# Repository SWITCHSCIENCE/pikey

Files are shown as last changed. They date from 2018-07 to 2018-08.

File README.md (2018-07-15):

# Pikey

This is 30 keys Keyboard and enclosure with integrated stand for Raspberry Pi 2,3,3+ and 3.5 inch display.

* PCB
	* Gerber data
	* KiCad project
	* Schematic
	* Artwork
	* BOM
* Firmware
	* QMK Keyboard source file
* Document
	* Not yet.
* 3D model
	* STL file
	* [Tinkercad](https://www.tinkercad.com/things/kkT37oe7HXW)

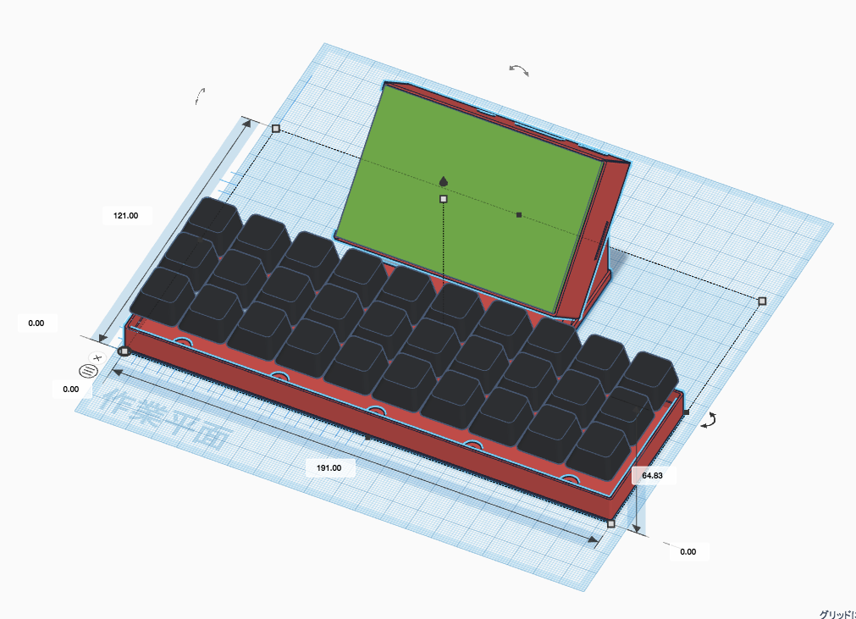
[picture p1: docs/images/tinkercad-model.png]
完成予定


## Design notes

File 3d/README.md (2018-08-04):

3x10 Cherry MX compatible Keyboard with Raspberry Pi and several kind of displays.

* PikeyHiPix4
	Pimoroni HyperPixel 4
	https://www.tinkercad.com/things/fxrJvk6TXBG

* PikeyHyPix3.5
	Pimoroni HyperPixel 3.5
	https://www.tinkercad.com/things/kfZhMOrKK17

* PikeyUCtronics3.5
	UCtronics 3.5
	https://www.tinkercad.com/things/gSCO0fujyfa

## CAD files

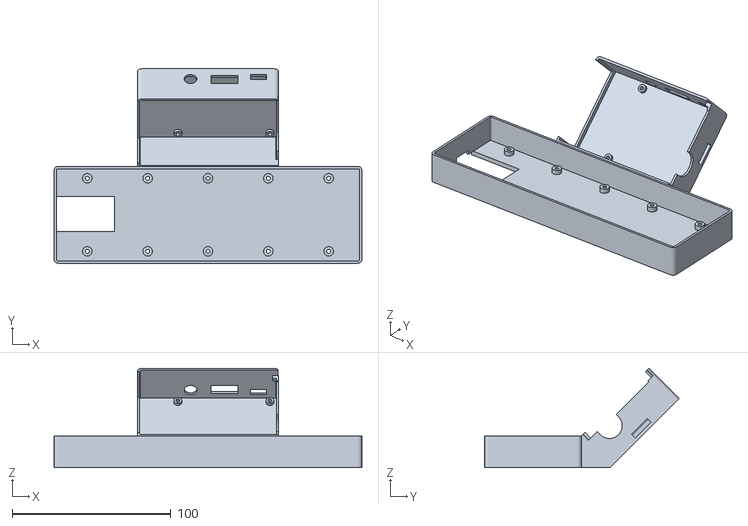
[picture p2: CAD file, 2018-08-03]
3d/PikeyHPix3.5.stl
194.0 x 122.5 x 62.5

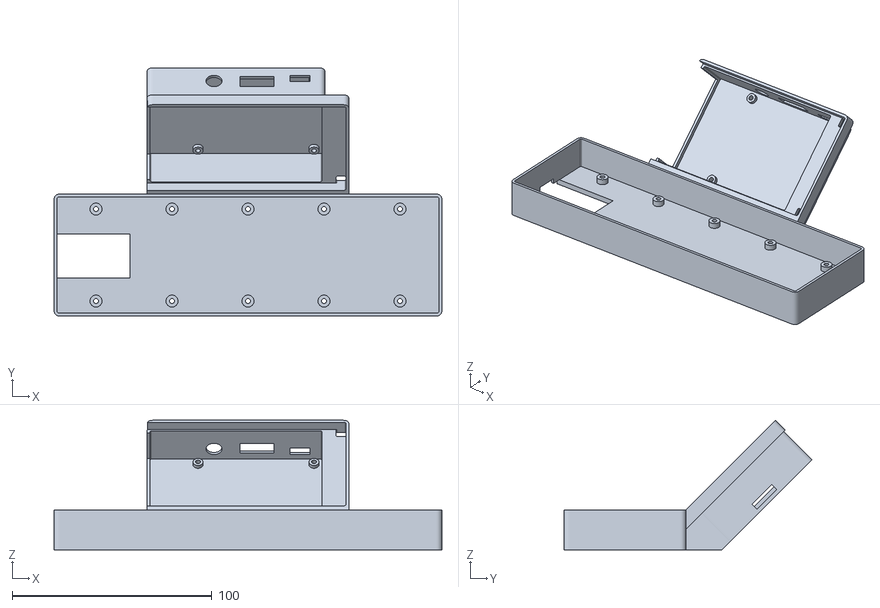
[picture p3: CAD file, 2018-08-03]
3d/PikeyHiPix4.stl
194.0 x 124.1 x 64.8

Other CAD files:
3d/PikeyUKtronics3.5.stl

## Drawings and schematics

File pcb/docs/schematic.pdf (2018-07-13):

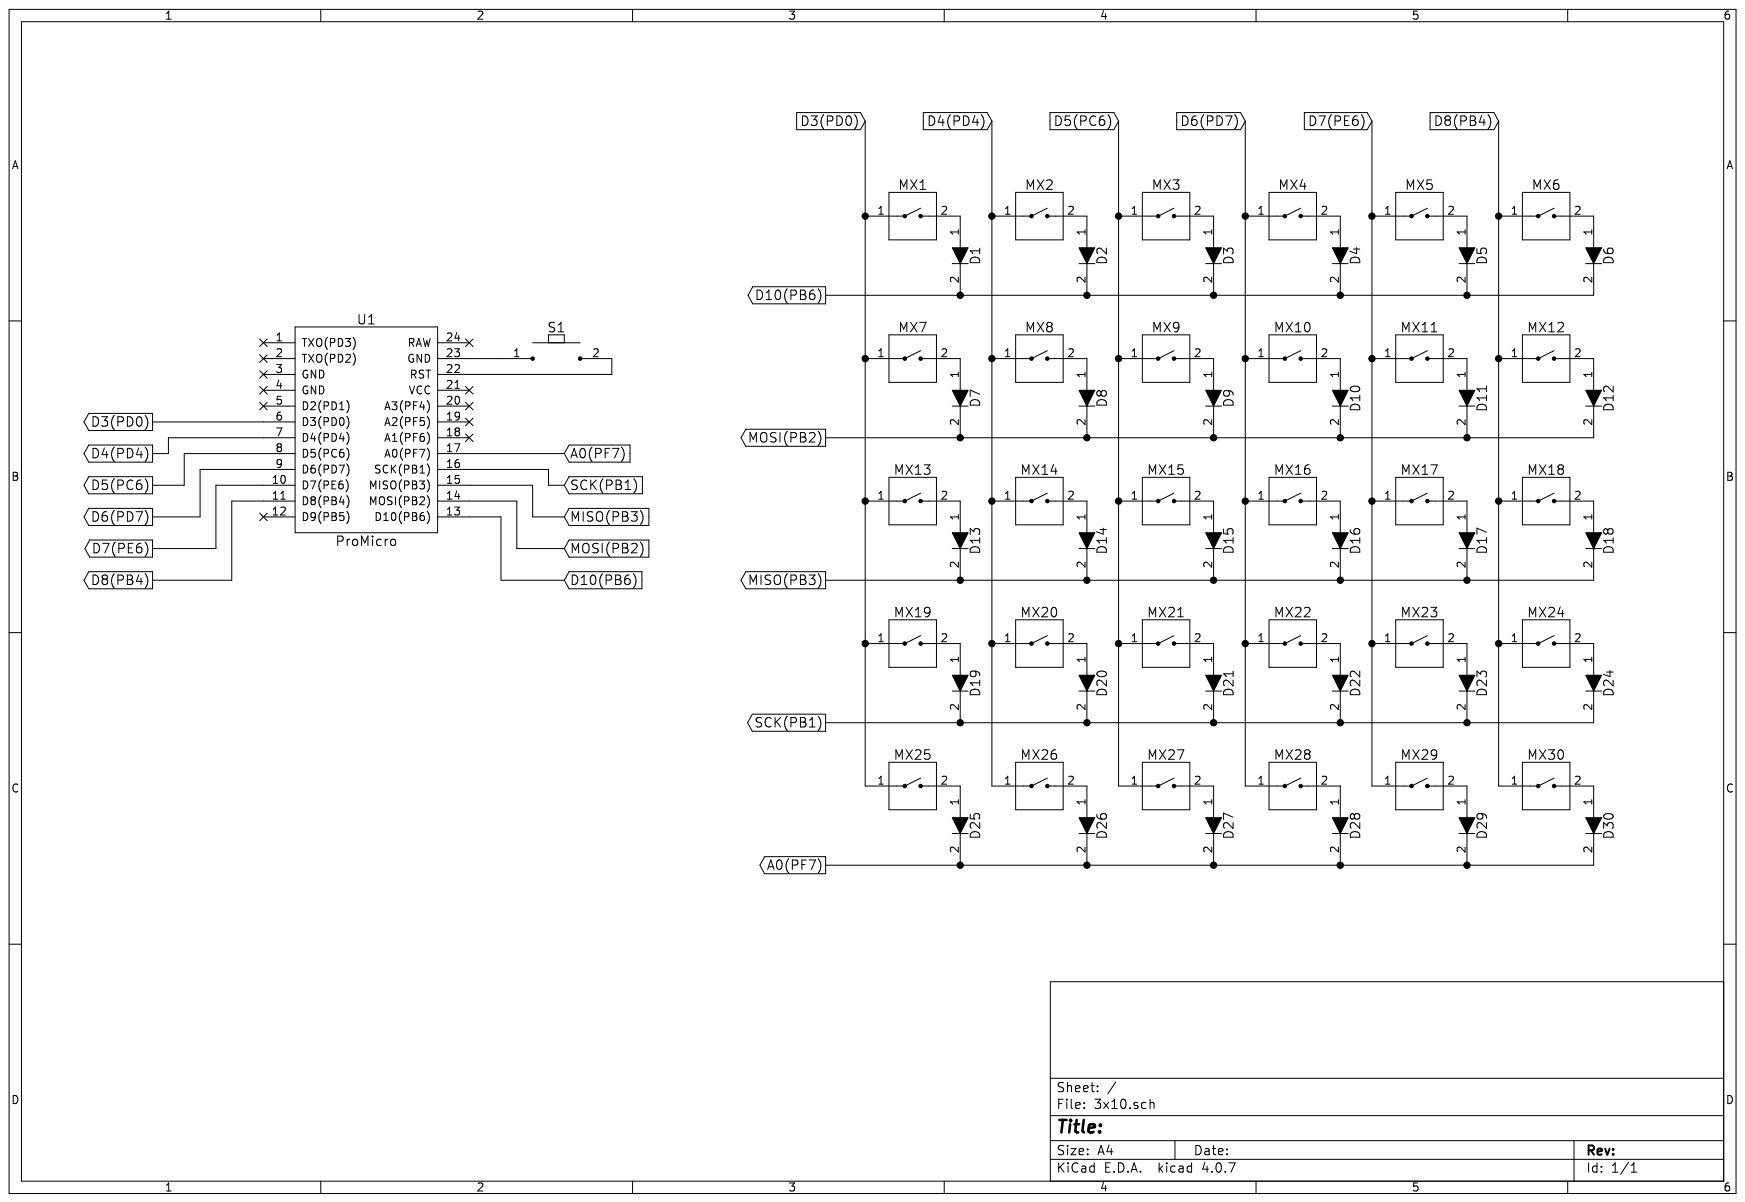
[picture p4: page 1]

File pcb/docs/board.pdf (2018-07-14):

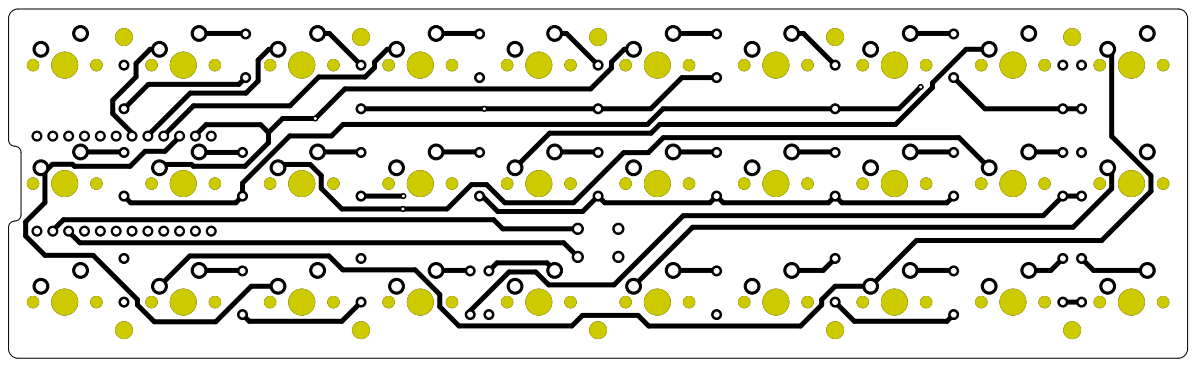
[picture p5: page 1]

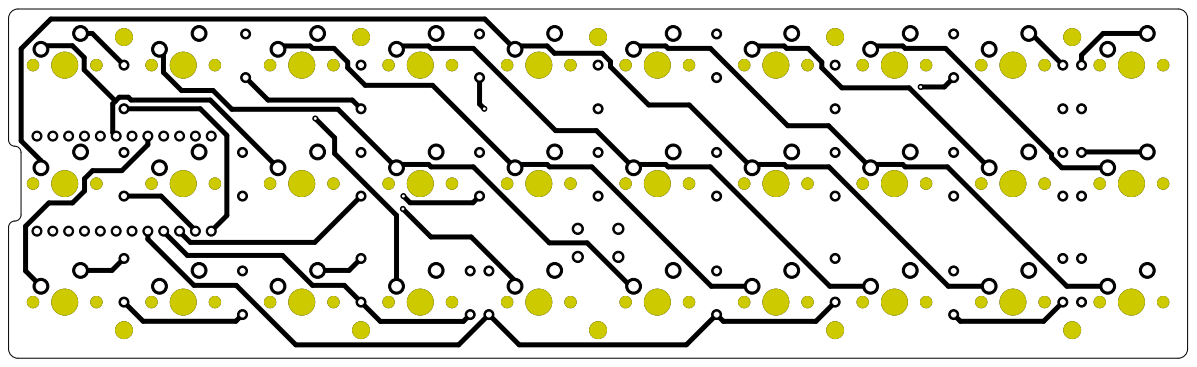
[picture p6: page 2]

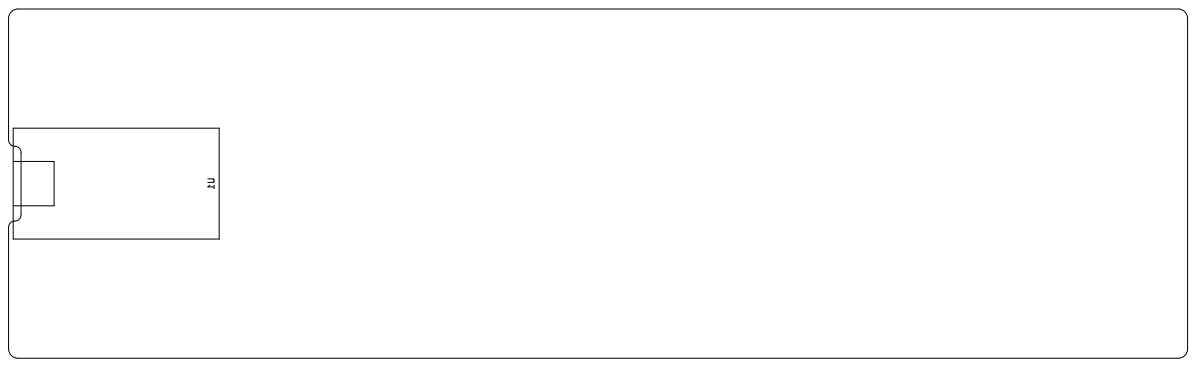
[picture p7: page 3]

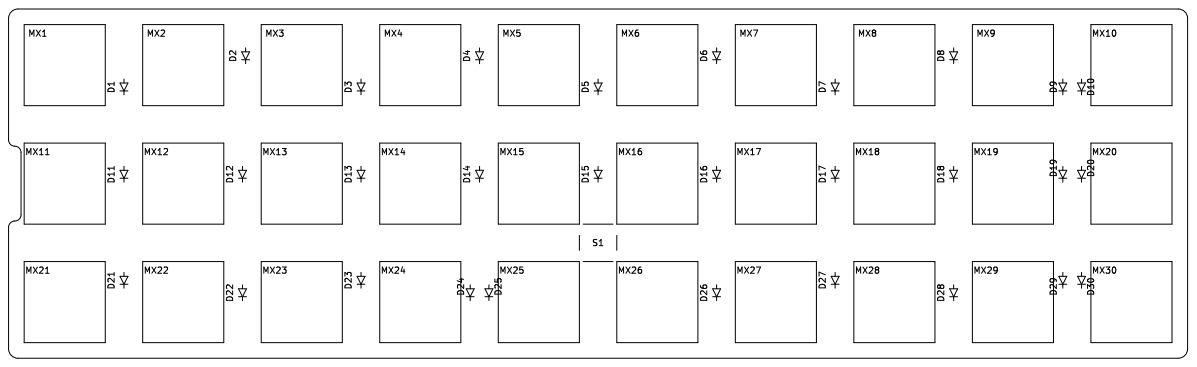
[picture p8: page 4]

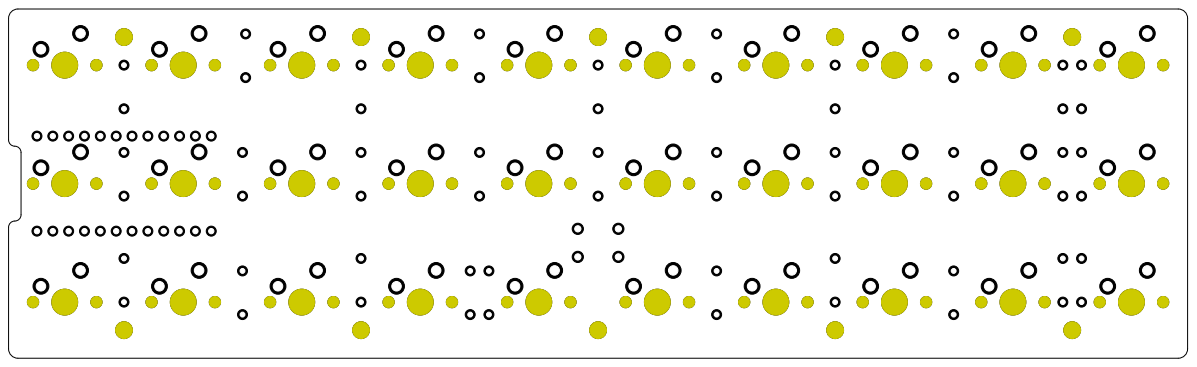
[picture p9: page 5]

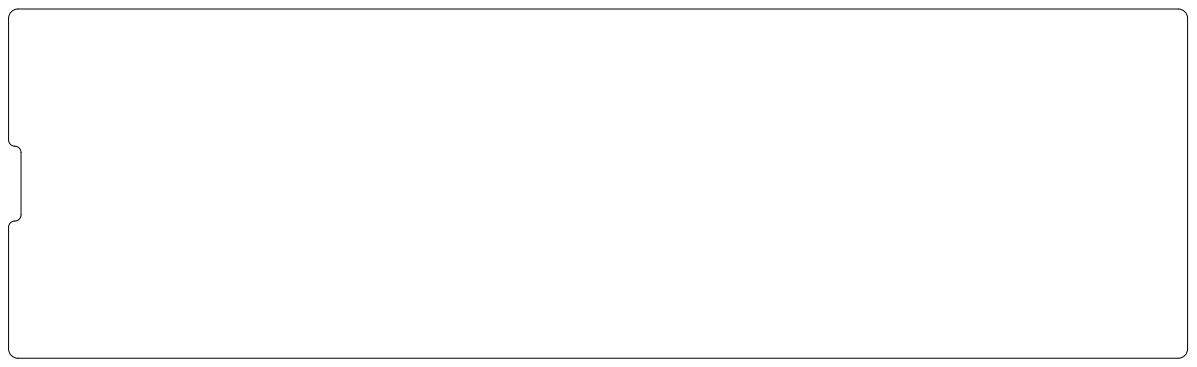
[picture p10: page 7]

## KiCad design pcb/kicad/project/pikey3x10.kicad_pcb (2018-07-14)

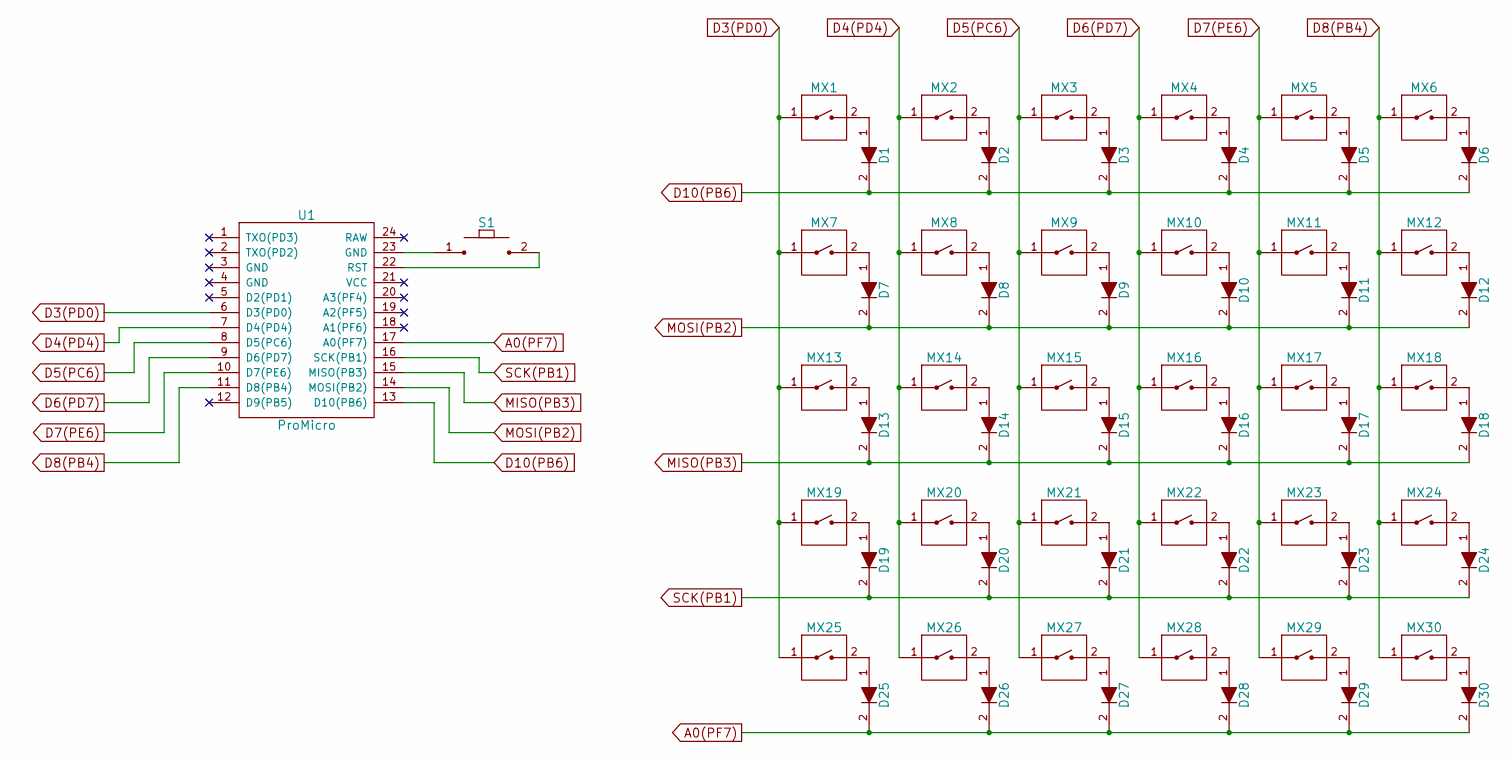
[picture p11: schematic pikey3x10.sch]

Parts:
D1, D2, D3, D4, D5, D6, D7, D8, D9, D10, D11, D12, D13, D14, D15, D16, D17, D18, D19, D20, D21, D22, D23, D24, D25, D26, D27, D28, D29, D30: diode
MX1, MX2, MX3, MX4, MX5, MX6, MX7, MX8, MX9, MX10, MX11, MX12, MX13, MX14, MX15, MX16, MX17, MX18, MX19, MX20, MX21, MX22, MX23, MX24, MX25, MX26, MX27, MX28, MX29, MX30: keyswitch
S1: tactswitch
U1: ProMicro; promicro

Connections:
A0(PF7): D25.2, D26.2, D27.2, D28.2, D29.2, D30.2, U1.17 (A0(PF7))
D3(PD0): MX1.1, MX7.1, MX13.1, MX19.1, MX25.1, U1.6 (D3(PD0))
D4(PD4): MX2.1, MX8.1, MX14.1, MX20.1, MX26.1, U1.7 (D4(PD4))
D5(PC6): MX3.1, MX9.1, MX15.1, MX21.1, MX27.1, U1.8 (D5(PC6))
D6(PD7): MX4.1, MX10.1, MX16.1, MX22.1, MX28.1, U1.9 (D6(PD7))
D7(PE6): MX5.1, MX11.1, MX17.1, MX23.1, MX29.1, U1.10 (D7(PE6))
D8(PB4): MX6.1, MX12.1, MX18.1, MX24.1, MX30.1, U1.11 (D8(PB4))
D10(PB6): D1.2, D2.2, D3.2, D4.2, D5.2, D6.2, U1.13 (D10(PB6))
MISO(PB3): D13.2, D14.2, D15.2, D16.2, D17.2, D18.2, U1.15 (MISO(PB3))
MOSI(PB2): D7.2, D8.2, D9.2, D10.2, D11.2, D12.2, U1.14 (MOSI(PB2))
unnamed: D1.1, MX1.2
unnamed: D2.1, MX2.2
unnamed: D3.1, MX3.2
unnamed: D4.1, MX4.2
unnamed: D5.1, MX5.2
unnamed: D6.1, MX6.2
unnamed: D7.1, MX7.2
unnamed: D8.1, MX8.2
unnamed: D9.1, MX9.2
unnamed: D10.1, MX10.2
unnamed: D11.1, MX11.2
unnamed: D12.1, MX12.2
unnamed: D13.1, MX13.2
unnamed: D14.1, MX14.2
unnamed: D15.1, MX15.2
unnamed: D16.1, MX16.2
unnamed: D17.1, MX17.2
unnamed: D18.1, MX18.2
unnamed: D19.1, MX19.2
unnamed: D20.1, MX20.2
unnamed: D21.1, MX21.2
unnamed: D22.1, MX22.2
unnamed: D23.1, MX23.2
unnamed: D24.1, MX24.2
unnamed: D25.1, MX25.2
unnamed: D26.1, MX26.2
unnamed: D27.1, MX27.2
unnamed: D28.1, MX28.2
unnamed: D29.1, MX29.2
unnamed: D30.1, MX30.2
unnamed: S1.1, U1.23 (GND)
unnamed: S1.2, U1.22 (RST)
SCK(PB1): D19.2, D20.2, D21.2, D22.2, D23.2, D24.2, U1.16 (SCK(PB1))

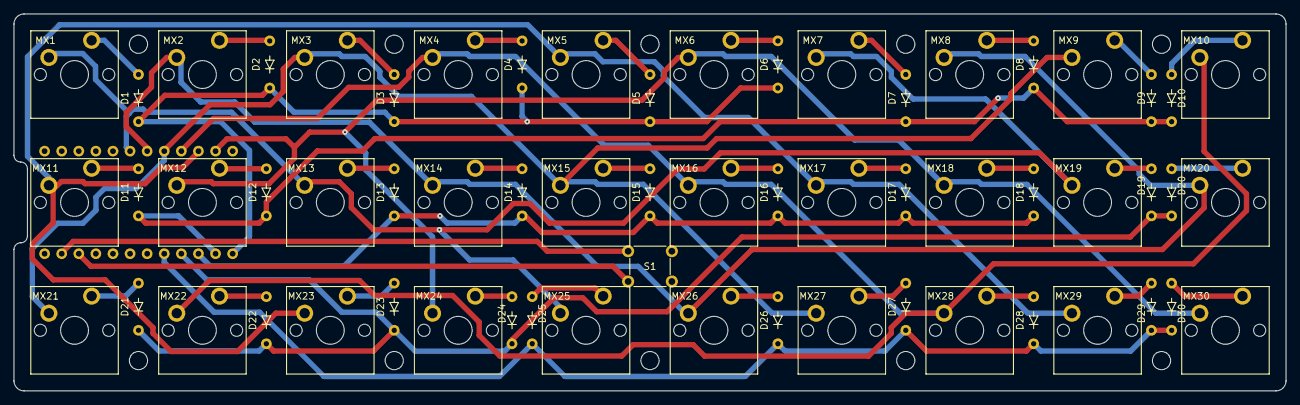
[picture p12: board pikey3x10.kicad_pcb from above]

Board: 2 copper layers, 189.0 x 56.0 mm, 72 parts (1 on the bottom side), 43 nets.

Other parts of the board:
h1, h2, h3, h4, h5, h6, h7, h8, h9, h10: MountingHole_2.7mm_M2.5

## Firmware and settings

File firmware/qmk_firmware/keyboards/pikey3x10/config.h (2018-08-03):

#ifndef CONFIG_H
#define CONFIG_H

#include "config_common.h"

/* USB Device descriptor parameter */
#define VENDOR_ID       0xFEED
#define PRODUCT_ID      0x0310
#define DEVICE_VER      0x0001
#define MANUFACTURER    Switch Science
#define PRODUCT         Pikey3x10
#define DESCRIPTION     A 30 key ortholinear keyboard, Gherkin clone

/* key matrix size */
#define MATRIX_ROWS 5
#define MATRIX_COLS 6

/* key matrix pins */
#define MATRIX_ROW_PINS { B6, B2, B3, B1, F7 }
#define MATRIX_COL_PINS { D0, D4, C6, D7, E6, B4 }
#define UNUSED_PINS

/* COL2ROW or ROW2COL */
#define DIODE_DIRECTION COL2ROW

/* Set 0 if debouncing isn't needed */
#define DEBOUNCING_DELAY 5

/* Mechanical locking support. Use KC_LCAP, KC_LNUM or KC_LSCR instead in keymap */
#define LOCKING_SUPPORT_ENABLE

/* Locking resynchronize hack */
#define LOCKING_RESYNC_ENABLE

/* key combination for command */
#define IS_COMMAND() ( \
    keyboard_report->mods == (MOD_BIT(KC_LSHIFT) | MOD_BIT(KC_RSHIFT)) \
)

/* prevent stuck modifiers */
#define PREVENT_STUCK_MODIFIERS

#endif

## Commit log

2018-07-13 add BOM
    [bom.xls]
2018-07-14 0.8mmのトレースに変更、不要なKiCadファイルの削除、ガーバー再作成
    [3x10.dsn, 3x10.kicad_pcb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]
2018-07-15 add 3D model
    [RasPiKey-3rd.stl]
2018-07-15 Add USB hole to 3D
    [RasPiKey-3rd.stl]
2018-07-19 3d update
    [Pikey Fat.stl, Pikey.stl]
2018-07-19 pcb update
    [3x10.gbl, 3x10.gbo, 3x10.gbs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]
2018-07-19 add gerber.zip
2018-07-19 update 3D model
    [Pikey Fat.stl]
2018-07-19 change name to pikey3x10
    [3x10.kicad_pcb, 3x10.sch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]
2018-08-03 changed Readme and BOM
    [PikeyHPix3.5.stl, PikeyHiPix4.stl, PikeyUKtronics3.5.stl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]
